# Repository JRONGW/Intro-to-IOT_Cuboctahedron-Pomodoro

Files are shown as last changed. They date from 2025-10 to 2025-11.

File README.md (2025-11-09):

# Cuboctahedron Pomodoro

A4 cuboctahedron

- The core functionality of the Cuboctahedron Pomodoro is using it as a timer for work and rest. Cuboctahedron is a symmetrical geometry representing the bi-mode of this pomodoro with its 6 identical squares and 8 identical triangles. The larger square surface down sets a 25min clock for work. The smaller triangle surface down sets a 5min clock for rest. In the testing, I use the 20s as a substitution for 25min clock and 10s as a substitution for 5min clock.

### Instruction for users
- Place the object with a square face down to start a work session.
- Place it with a triangle face down to start a rest session.
- Hold a face steady for 10 s (demo mode) to confirm; LEDs and the website visualize the state.
- (Production timings: 25 min work, 5 min rest; demo timings: 20 s / 10 s.)

### Merits
- It connects physical interaction, edge computing, event-driven networks and visualization into a closed loop.
- Edge-side filtering + hysteresis + dwell time can eliminate "false triggering" at the device end and reduce the noise of uplink data (the value of edge computing).
Robustness
####  Robustness1: Unit-vector normalization + zero-guard: 
- I compute n2 and bail if it’s ≈0, then normalize → prevents NaNs and ensures stable dot products. If I don’t normalize the accelerometer vector, the direction test gets contaminated by magnitude, which breaks thresholds, hysteresis, and dwell logic. Because the thresholds are set assuming that the n2 is normalized
####  Robustness2: LPF + re-normalize: 
- exponential smoothing (LPF_ALPHA) damps jitter; re-normalizing keeps math stable.
####  Robustness3: Hysteresis (ENTER_TH/EXIT_TH): 
- avoids flicker when the score hovers near the threshold.
####  Robustness4: 10-second dwell confirmation (DWELL_MS): 
- suppresses false triggers from bumps.
####  Robustness5: Re-arm dip (REARM_DROP_MS)
- After confirming a face, don’t consider any new face until the current face’s score has dipped below a lower threshold (EXIT_TH) for at least REARM_DROP_MS milliseconds.
####  Robustness6: Last-confirmed suppression: 
- ignores the same face immediately after confirming it to prevent repeats.

### Demerits
- The function of the pomodoro needs to be explained to the user.

### Message to MQTT
#### 1)72-LED frame bytes (binary)
 - Topic: student/CASA0014/luminaire/<user>
 - (built into mqtt_data_topic as "%s/%d" % (mqtt_base_topic, LUMINAIRE_USER))
 - Payload: raw binary buffer frameBuf of length 216 bytes (= 72 LEDs × 3 bytes per LED).
 - Format per LED: GRB order (that’s how NeoPixel expects it):
 - [G0, R0, B0,  G1, R1, B1,  ...  G71, R71, B71]
 - When sent: every time  call publishFrame() from  effect loops.
 - It shows as a blob of bytes that can be toggled to hex

#### 2)JSON “telemetry/commands” for status/timer
- These are the two snprintf(...) payloads published to mqtt_cmd_topic:
- Timer/transition message (called in updateEffects() when switching modes):
 - Example payload:
 - {"device":"MKR1010_Cubo_FaceEffects","cmd":"timer","palette":"row_temporal_grad","seconds":20,"face":"+X"}
 - {"device":"MKR1010_Cubo_FaceEffects","cmd":"timer","palette":"grad_chaser","seconds":0,"face":"square"}
- State/lock message (sent on 10-second confirmation):
 -  {"device":"MKR1010_Cubo_FaceEffects","cmd":"state","face":"+X","type":"square","score":0.913,"valid":true,"locked":true}

#### 3)Control inputs to listen for: /user and /brightness (plain numbers).

### Design
- The design follows the design principle that form follows functions in architecture. This geometry works as an abstract switch with correspondence from shape to time. 
- The larger surface with 4 edges means a longer time of working mode. The smaller surface with 3 edges means a shorter time of working mode.

### What I learned
- While making my prototype, I learned to design an algorithm to distinguish the faces from the sensor data. I tried ypr angles and acceleration. The acceleration worked. 

#### Algorithm for face detection using acceleration from IMU(MPU 6050)
- Maximizing -cos(θ) finds the θ when θ ≈ π (180°): the vectors are opposite.
- So the code is effectively finding the face whose outward normal n is most opposite to gravity g—equivalently, the face whose inward normal -n is most aligned with g.
- It’s picking the one closest to -N6[i] (i.e., the face that’s pointing down). The same logic is then repeated for the 8 triangle-face normals in N8.

 

# Circuit in Progress





# Video of Progress



Face detection tested successfully:
https://github.com/user-attachments/assets/b0937933-bc55-468b-9377-7d1f1f2e085a



Cuboctahedron Pomodoro to Vespera
https://github.com/user-attachments/assets/1aa174da-ec46-4a6b-9827-48664f9fa585



Effects updated
https://github.com/user-attachments/assets/3790d0ce-7d41-47c6-a9a7-6038a02cd146



Lid, button, and Lipo battery added, timer is represented with a gradual fill
https://github.com/user-attachments/assets/802b1e29-6ce2-49ec-8bdd-a41c0206a4fa

# Code for Face Detection, MQTT Connection, and Light Control - lightconnect.ino
## Hardware/Overall Structure
- Device Layer: MKR WiFi 1010 (WiFiNINA module + on-board RGB), MPU-6050 (accelerometer).
- Connection Layer: MQTT (tcp 1884).
- Application Layer: 72-pixel matrix web page + Vespera device (216-byte RGB frame), achieving synchronous visualization of "digital twin".

## 72 Pixels and Frame Buffer
- One-dimensional buffer frameBuf[216], logically mapped as 6 rows × 12 columns.
- Index function: idxFromRowCol(r,c) = c*6 + r (column-major order, 6 pixels per column).
- After each rendering, it is pushed to the web page/device via mqttClient.publish(mqtt_data_topic, frameBuf, 216).

## Wi-Fi and MQTT connection
- The `ensureWiFi()` function continuously attempts to connect; once successful, it lights up the on-board green LED (PWM pins 25/26/27 of NINA). 
- The `ensureMQTT()` function tries to connect every 5 seconds; upon success, it subscribes to three types of topics.

## IMU orientation determination ("which side is down")
### Sampling and Normalization
- Read the raw acceleration (ax, ay, az), and normalize it to (gx, gy, gz) ≈ the gravity direction vector at 16384 LSB/g.
- Low-pass filtering: Apply a first-order IIR smoothing with LPF_ALPHA = 0.20 and renormalize to suppress jitter.
### Face Vector Library
- 6 square face normals: ±X, ±Y, ±Z.
- 8 triangular face normals: Unit vectors in the cube's body diagonal directions (±1, ±1, ±1)/√3.
### Matching Criterion: Seek the face with the maximum -dot(n, g).
- If a face normal n is approximately opposite to the current gravity g, a larger -dot(n, g) indicates that the face is more "correctly" facing down.
### Hysteresis and Stability
- Enter threshold ENTER_TH = 0.80, exit threshold EXIT_TH = 0.72 (to prevent oscillation).
- Prevent "re-triggering on the same face": After confirming a face, the next confirmation must be on a different face.
### Dwell Confirmation (to avoid false triggers)
- A confirmation is only made after remaining on the same candidate face for 10 seconds (DWELL_MS).
- Upon confirmation, start the corresponding visual program (square → work mode, triangle → rest mode).

# Testing Codes
### Test I²C - I2Cscanner0.ino
- That’s an I²C bus scanner. It tests whether anything is alive on the I²C lines and what 7-bit addresses they respond to.
- What it verifies:
-   Wiring & power: SDA/SCL connected correctly, device powered, grounds tied together.
-   Device presence & address: prints any responding address (e.g., MPU-6050 at 0x68; 0x69 if AD0=HIGH).
-   Bus health: if nothing shows, there may be shorts, missing pull-ups, wrong voltage, or a stuck device.

### Test MPU-6050 and I²C wiring - minimaltestMakeINTeasytocatch.ino
- This sketch is a hardware/debug probe for  MPU-6050 DATA_RDY interrupt and I²C wiring. It checks three things:
- What it sets up
-   I²C comms to the MPU-6050 at address 0x68 (change to 0x69 if AD0=HIGH).
-   INT pin behavior on the MPU:
-   Enables DATA_RDY interrupt (INT_ENABLE = 0x01).
-   Tries to set: active-HIGH, push-pull, latched until cleared, clear-on-INT_STATUS read (via the library calls).
-   MCU interrupt line: connects MPU’s INT pin → MKR1010 D2, and attaches attachInterrupt(..., RISING) to catch edges.
- What it prints (and why)
-   On setup() it reads key registers directly (even if the lib lacks getByte):
-   WHO_AM_I → should be 0x68 (or 0x69 depending on variant).
-   PWR_MGMT_1 → expect 0x00 if not sleeping.
-   INT_ENABLE → expect 0x01 (DATA_RDY enabled).
-   INT_PIN_CFG → shows pin config bits (latch, polarity, etc.).

### Test MPU-6050 angle - mpu6050_mkr1010_new.ino
-   This tests printing the ypr angles from MPU-6050

### Test the face detection with UNO when MKR1010 is broken - unotest.ino
-   This tests which face is down using MPU-6050 and Arduino UNO

### Test the face detection with UNO when MKR1010 is broken - quickserialsanitytest.ino
-   It’s a tiny Serial + timing test for MKR1010.
-   What it verifies:
-   USB Serial link works: Serial.begin(115200) opens the port; 
-   while (!Serial) {} waits until the Serial Monitor is opened.
-   Board is running and not crashing: you’ll see a steady stream of prints.
-   Timing with millis() is sane: it prints once per second using a non-blocking timer.

### Test the MPU-6050 exporting - MPU6050exporttest.ino
-   I²C wiring & power
-     Wire.begin(); Wire.setClock(400000); mpu.initialize(); mpu.testConnection()//Confirms the chip responds on I²C (0x68/0x69) at 400 kHz.
-   DMP firmware load & configuration

-     mpu.dmpInitialize(); mpu.setDMPEnabled(true); packetSize = mpu.dmpGetFIFOPacketSize();//Ensures the on-chip DMP successfully boots and outputs fixed-size packets (typically 42 bytes).
-   FIFO health
-     fifoCount = mpu.getFIFOCount(); ... if (fifoCount == 1024) resetFIFO();//Checks for overflows
-   Quaternion → gravity → YPR math
-     dmpGetQuaternion(&q, fifoBuffer);
-     dmpGetGravity(&gravity, &q);
-     dmpGetYawPitchRoll(ypr, &q, &gravity);//Confirms the DMP orientation solution is coherent and  derives yaw, pitch, roll.
-   Streaming/throughput check: prints YPR at ~20 Hz (if (now - last >= 50)) to make sure Serial USB isn’t the bottleneck.

## Effect state machine (EFFECT_*)
-   EFFECT_SQUARE (20 s): "Row scan + row color breathing"
-   EFFECT_TRIANGLE (10 s): "Veered single-pixel column drift" (added the veeredSinglePerColGradient effect)
-   EFFECT_YELLOW: "5-pixel gradient chase (black ↔ yellow ↔ black)"

## Effect functions
### Row "Blink Through" Gradient - rowBlinkThrough()
-   Core idea: Instead of moving the "gradient stripes", the active row/column itself "breathes" between colors A and B over time.
-   Background: Static gradient from white to the target color (row: #FBE9D7; column: #E0F4FF) to enhance the layering effect.
-   Renderer:
-   rowBlinkThrough(r, a, b, bgTarget, t): First draw the column-wise gradient for the entire background, then overlay the r-th row with lerp(a, b, t).

### diagonal drift single pixel + vertical halo - veeredSinglePerColGradient()
-   veeredSinglePerColGradient(startCol, windowCols, baseRow, veer, a, b, radius)
-   Each column lights up one pixel and scrolls with time starting from startCol.
-   Every DRIFT_EVERY steps, baseRow moves down, forming a diagonal "snake-like" drift.
-   The upper and lower parts of the same column create a halo that gradually fades to black with a radius, enhancing the three-dimensional effect.
-   Visually, it is more dynamic than fixed "column strips".

### The "Chaser" and "Flip Every Lap" - chaserWindow()
-   chaserWindow(start, 5, a, b): A 5-pixel window advances in a 72-pixel loop.
-   chaseFlip flips a ↔ b every lap, creating an alternating pattern of light blue ↔ black ("color change every lap").
-   synchronized the on-board RGB to the tail color cB, creating a mini debug/heartbeat indicator, which is very practical.

# Design Files
-   Cuboctahedron Components folder - contains stl files of componets
-   Cuboctahedron Pomodoro.3dm -  cuboctahedron pomodoro prototype model file

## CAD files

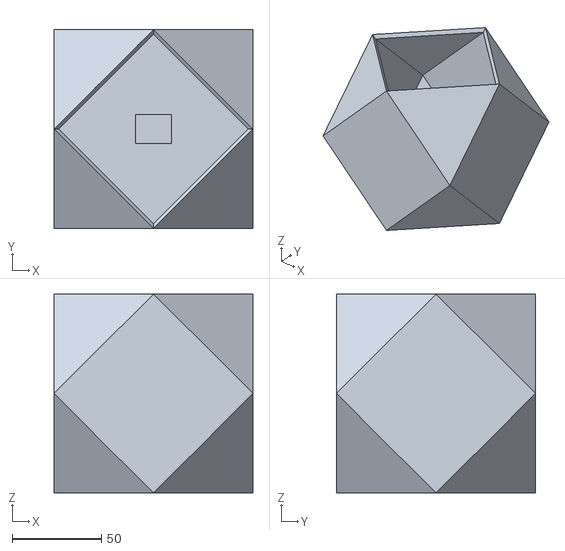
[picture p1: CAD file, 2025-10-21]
Cuboctahedron Components/main.stl
111.4 x 111.4 x 111.4

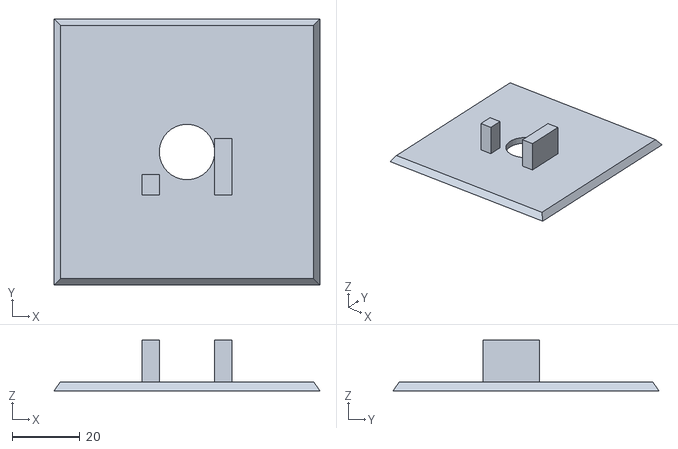
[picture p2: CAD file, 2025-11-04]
Cuboctahedron Components/lidwithhole.stl
78.7 x 78.8 x 15.0

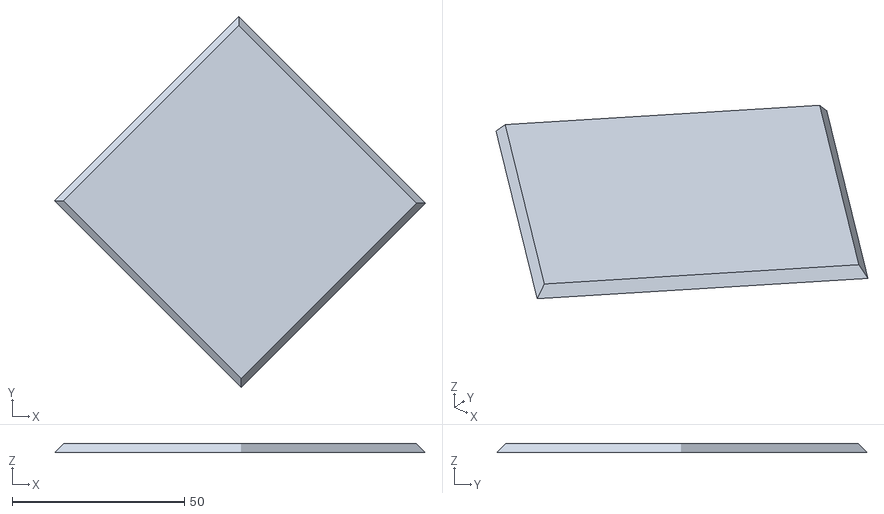
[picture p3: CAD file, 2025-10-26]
Cuboctahedron Components/lid2.stl
107.8 x 107.8 x 2.65

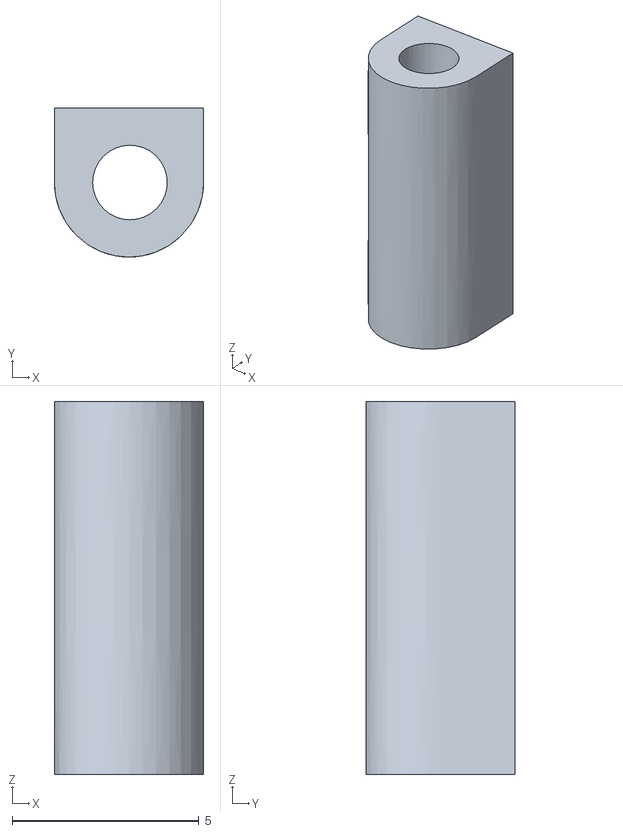
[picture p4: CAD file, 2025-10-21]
Cuboctahedron Components/hinge2.stl
4.00 x 4.00 x 10.0

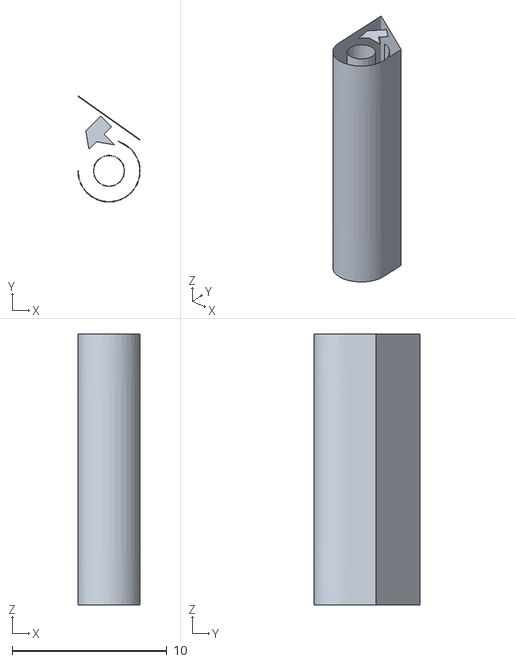
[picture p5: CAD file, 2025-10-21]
Cuboctahedron Components/hinge1.stl
4.00 x 6.83 x 17.5

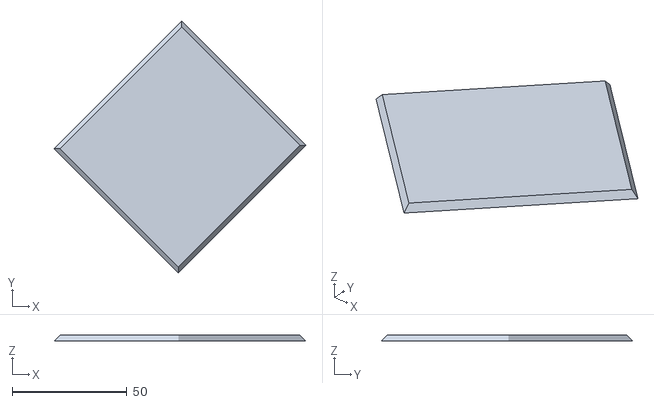
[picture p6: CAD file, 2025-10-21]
Cuboctahedron Components/lid.stl
110.0 x 110.0 x 2.65

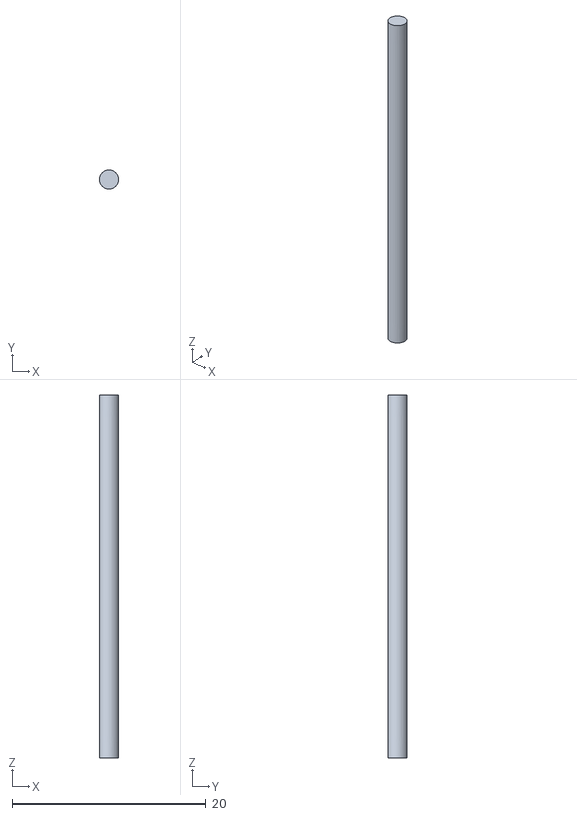
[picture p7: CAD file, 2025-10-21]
Cuboctahedron Components/pole.stl
1.98 x 1.98 x 37.5

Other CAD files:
Cuboctahedron Components/lidwithhole.gcode.3mf
Cuboctahedron Components/Lidwithhole.3dm
Cuboctahedron Components/lid with button hole.3dm
Cuboctahedron Pomodoro.3dm

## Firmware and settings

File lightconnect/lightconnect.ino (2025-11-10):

/***************************************************************
 * MKR WiFi 1010 + MPU-6050 (GY-521) — Cuboctahedron Face Detection
 * + WiFiNINA + MQTT (tcp 1884) + 72-pixel Website Effects
 *
 * Square DOWN   → Row blink-through #F6D5F7 ↔ #FBE9D7 (white→#FBE9D7 bg)
 * Triangle DOWN → Column blink-through #CAD0FF ↔ #E0F4FF (white→#E0F4FF bg)
 * Then 5-pixel gradient chaser that alternates light blue ↔ black each lap
 ***************************************************************/
#include <Wire.h>
#include <math.h>
#include "I2Cdev.h"
#include "MPU6050.h"

#include <SPI.h>
#include <WiFiNINA.h>
#include <PubSubClient.h>
#include <Adafruit_NeoPixel.h>
#include <utility/wifi_drv.h>

#include "arduino_secrets.h"  // SECRET_SSID / SECRET_PASS (+ optional MQTT_USERNAME / MQTT_PASSWORD)

/********* WIFI *********/
char ssid[] = SECRET_SSID;
char pass[] = SECRET_PASS;

/********* MQTT *********/
static const char* MQTT_HOST = "mqtt.cetools.org";
static const int   MQTT_PORT = 1884;  
static const char* MQTT_CLIENTID = "MKR1010_Cubo_FaceEffects";

#ifdef MQTT_USERNAME
  #define HAS_MQTT_AUTH 1
#else
  #define HAS_MQTT_AUTH 0
#endif

WiFiClient wifiClient;
PubSubClient mqttClient(wifiClient);

/********* Topics *********/
const char* mqtt_cmd_topic         = "student/CASA0014/luminaire/cmd";
const char* mqtt_base_topic        = "student/CASA0014/luminaire";
const char* user_update_topic      = "student/CASA0014/luminaire/user";
const char* brightness_update_topic= "student/CASA0014/luminaire/brightness";

/********* User & local-mirror *********/
int  LUMINAIRE_USER       = 25;   // change if needed
int  LUMINAIRE_BRIGHTNESS = 150;  // 0..255 (local mirror only)
char mqtt_data_topic[64];         // student/CASA0014/luminaire/<user>

/********* Website “virtual strip” *********/
#define NEOPIXEL_COUNT 72
#define NEOPIXEL_DATA_LENGTH (NEOPIXEL_COUNT * 3)
uint8_t frameBuf[NEOPIXEL_DATA_LENGTH];

/********* Optional local mirror strip *********/
#define NEOPIXEL_PIN 6
Adafruit_NeoPixel pixels(NEOPIXEL_COUNT, NEOPIXEL_PIN, NEO_GRB + NEO_KHZ800);

/********* IMU *********/
MPU6050 mpu;  // default address 0x68

/********* FACE NORMALS *********/
const float N6[6][3] = {
  { 1, 0, 0 }, { -1, 0, 0 }, { 0, 1, 0 }, { 0, -1, 0 }, { 0, 0, 1 }, { 0, 0, -1 }
};
const char* N6name[6] = { "+X", "-X", "+Y", "-Y", "+Z", "-Z" };

const float sN = 0.57735026919f;  // 1/sqrt(3)
const float N8[8][3] = {
  { sN, sN, sN }, { sN, sN, -sN }, { sN, -sN, sN }, { sN, -sN, -sN },
  { -sN, sN, sN }, { -sN, sN, -sN }, { -sN, -sN, sN }, { -sN, -sN, -sN }
};
const char* N8name[8] = {
  "+ + +", "+ + -", "+ - +", "+ - -",
  "- + +", "- + -", "- - +", "- - -"
};

/********* Detection thresholds & timing *********/
const float ENTER_TH   = 0.80f;
//entry threshold for detecting a face as ‘down’
//arccos(0.80) ≈ 36.9°

const float EXIT_TH    = 0.72f;
//exit threshold for leaving that face
//arccos(0.72) ≈ 44.0°

//So a face is conunted as ‘down’ if its normal is within 36.9 degrees
//It stays down until you tilt it past 44 degrees

// ENTER_TH and EXIT_TH creates a 7.1 degree hysteresis band that prevents flicker/rapid toggling when you are near the boundary


const float LPF_ALPHA  = 0.20f;
//this is the smoothing factor for the exponential 
//moving average(EMA) on the gravity vector

const unsigned long DWELL_MS       = 10000UL;  // 10 s confirm
const unsigned long REARM_DROP_MS  = 800UL;

struct FaceState {
  bool  isSquare;
  int   idx;
  float score;
};

static inline float invSqrt(float x) { return 1.0f / sqrtf(x); }
static inline bool sameFace(const FaceState& a, const FaceState& b) {
  return (a.idx == b.idx) && (a.isSquare == b.isSquare);
}

/*** Detection state ***/
FaceState currentFace   = { true, -1, -1.0f };
bool      haveLPF       = false;
float     gx_f=0, gy_f=0, gz_f=0;

FaceState dwellCandidate= { true, -1, -1.0f };
unsigned long dwellStartMs = 0;

FaceState lastConfirmed = { true, -1, -1.0f };

unsigned long belowStartMs = 0;
bool belowActive = false;

/********* Effect program *********/
const unsigned long DURATION_SQUARE_MS   = 20000UL; // 20 seconds
const unsigned long DURATION_TRIANGLE_MS = 10000UL; // 10 seconds

const unsigned long SCAN_PERIOD_MS  = 150UL; // every 150 ms advance row/column
const unsigned long CHASE_PERIOD_MS = 80UL;  // every 80 ms advance chaser

bool programRunning = false, programIsSquare = false;
unsigned long programStart = 0, effectStartMs = 0;

unsigned long animStartTriangle = 0;

// button control
const int BTN_PIN = 7;          // D7 connected to DFR0785-G "D"
const unsigned long DEBOUNCE_MS = 30;
const bool BTN_ACTIVE_HIGH = true;   // if your reading is inverted, flip to false

volatile bool detectEnabled = true;
volatile bool g_logFrameOnce = false;   // reset at loop start; first publish prints

unsigned long btnLastChange = 0;
bool btnPrev = LOW;             // module idles LOW (not pressed)

//-----------
enum EffectMode { EFFECT_IDLE, EFFECT_SQUARE, EFFECT_TRIANGLE, EFFECT_YELLOW };
EffectMode effect = EFFECT_IDLE;

bool yellowLatched = false; 

// variables
int  scanRow  = 0;   // 0..5
int  scanCol  = 0;   // 0..11
int  chaseIdx = 0;   // 0..71
unsigned long lastStepMs = 0;

/*** Temporal gradient blink state ***/
float rowBlinkT = 0.0f; int rowBlinkDir = 1;
float colBlinkT = 0.0f; int colBlinkDir = 1;
const float BLINK_DELTA = 0.12f;

/********* Onboard RGB helpers (via NINA) — 25=R, 26=G, 27=B *********/
static inline void setRGB(uint8_t r, uint8_t g, uint8_t b) {
  WiFiDrv::pinMode(25, OUTPUT);
  WiFiDrv::pinMode(26, OUTPUT);
  WiFiDrv::pinMode(27, OUTPUT);
  WiFiDrv::analogWrite(25, r);
  WiFiDrv::analogWrite(26, g);
  WiFiDrv::analogWrite(27, b);
}
static inline void LedRed()    { setRGB(155, 0, 0); }
static inline void LedGreen()  { setRGB(0, 155, 0); }
static inline void LedBlue()   { setRGB(0, 0, 155); }
static inline void LedYellow() { setRGB(255, 255, 0); }
static inline void LedWhite()  { setRGB(255, 255, 255); }

/********* Color + FX helpers *********/
struct Color { uint8_t r, g, b; };
const Color WHITE = { 255, 255, 255 };

// Row gradient
const Color GRAD_ROW_A = { 0xFC, 0x99, 0xFF };  // #FC99FF
const Color GRAD_ROW_B = { 0xFF, 0xA7, 0x4F };  // #FFA74F

const Color GRAD_BG_A = {0xF8, 0x9B, 0x29}; // #F89B29 (top) 
const Color GRAD_BG_B = {0xE7, 0x61, 0xBD}; // #E761BD (bottom)

// Column gradient (not used in progressive, kept for compat)
const Color GRAD_COL_A = { 0xCA, 0xD0, 0xFF };  // #CAD0FF
const Color GRAD_COL_B = { 0xE0, 0xF4, 0xFF };  // #E0F4FF

// Chaser endpoints
const Color GRAD_CHASE_B = { 0xF8, 0xFF, 0xBD }; // #f8ffbd
const Color GRAD_CHASE_A = { 0x00, 0x00, 0x00 };  // black

// gradient for triangle surface (L→R)
const Color BG_LR_A = {0x83, 0xF5, 0xE5}; // #83F5E5 
const Color BG_LR_B = {0xE7, 0x61, 0xBD}; // #E761BD

class FX {
public:
  static inline Color lerp(const Color& a, const Color& b, float t) {
    if (t < 0) t = 0; if (t > 1) t = 1;
    Color c;
    c.r = (uint8_t)(a.r + (b.r - a.r) * t);
    c.g = (uint8_t)(a.g + (b.g - a.g) * t);
    c.b = (uint8_t)(a.b + (b.b - a.b) * t);
    return c;
  }

  static inline void fillSolid(uint8_t r, uint8_t g, uint8_t b) {
    for (int i = 0; i < NEOPIXEL_COUNT; i++) {
      frameBuf[i * 3 + 0] = r;
      frameBuf[i * 3 + 1] = g;
      frameBuf[i * 3 + 2] = b;
    }
  }
  

  static inline int idxFromRowCol(int r, int c) { return c * 6 + r; }

  // Row blink-through: background = ROW gradient (WHITE->bgTarget); active row = lerp(a,b,t)
  static void rowBlinkThrough(int r, const Color& a, const Color& b, const Color& bgTarget, float t) {
    if (r < 0) r = 0;
    if (r > 5) r = 5;

    // Fill background: each row has a single uniform color
    for (int rr = 0; rr < 6; rr++) {
      float tr = (6 > 1) ? (float)rr / 5.0f : 0.0f;   // 0..1 by row
      Color cc = lerp(WHITE, bgTarget, tr);
      for (int c = 0; c < 12; c++) {
        int i = idxFromRowCol(rr, c);
        frameBuf[i * 3 + 0] = cc.r;
        frameBuf[i * 3 + 1] = cc.g;
        frameBuf[i * 3 + 2] = cc.b;
      }
    }

    // Override active row with the blink color, uniformly across the row
    Color rc = lerp(a, b, t);
    for (int c = 0; c < 12; c++) {
      int i = idxFromRowCol(r, c);
      frameBuf[i * 3 + 0] = rc.r;
      frameBuf[i * 3 + 1] = rc.g;
      frameBuf[i * 3 + 2] = rc.b;
    }
  }

  // Progressive background fill (top → bottom):
  // - Rows [0 .. rowsToFill-1] show the top→bottom gradient color for that row.
  // - Rows [rowsToFill .. 5] remain WHITE (not yet revealed).
  // Then overlay the active blink row 'r'.
  static void rowBlinkThroughProgressive(int r, const Color& a, const Color& b, float t, int rowsToFill) {
    if (r < 0) r = 0;
    if (r > 5) r = 5;
    if (rowsToFill < 0) rowsToFill = 0;
    if (rowsToFill > 6) rowsToFill = 6;

    for (int rr = 0; rr < 6; rr++) {
      // Compute the per-row gradient factor (top=0 → bottom=1)
      float tr = (6 > 1) ? (float)rr / 5.0f : 0.0f;

      // If this row is already "revealed", use its gradient color; else keep white
      Color rowColor = (rr < rowsToFill) ? lerp(GRAD_BG_A, GRAD_BG_B, tr) : WHITE;

      // Paint the whole row with that color
      for (int c = 0; c < 12; c++) {
        int i = idxFromRowCol(rr, c);
        frameBuf[i * 3 + 0] = rowColor.r;
        frameBuf[i * 3 + 1] = rowColor.g;
        frameBuf[i * 3 + 2] = rowColor.b;
      }
    }

    // Overlay active row with the blink color (uniform across the row)
    Color rc = lerp(a, b, t);
    for (int c = 0; c < 12; c++) {
      int i = idxFromRowCol(r, c);
      frameBuf[i * 3 + 0] = rc.r;
      frameBuf[i * 3 + 1] = rc.g;
      frameBuf[i * 3 + 2] = rc.b;
    }
  }



  // X-pixel gradient chaser window; black elsewhere
  static void chaserWindow(int startIdx, int window, const Color& a, const Color& b) {
    fillSolid(0, 0, 0);
    if (window < 1) window = 1;
    for (int k = 0; k < window; k++) {
      int i = (startIdx + k) % NEOPIXEL_COUNT;
      float t = (window > 1) ? (float)k / (float)(window - 1) : 0.0f;
      Color cc = lerp(a, b, t);
      frameBuf[i * 3 + 0] = cc.r;
      frameBuf[i * 3 + 1] = cc.g;
      frameBuf[i * 3 + 2] = cc.b;
    }
  }

  static inline Color toGray(const Color& c) {
    uint8_t y = (uint8_t)((0.2126f * c.r) + (0.7152f * c.g) + (0.0722f * c.b) + 0.5f);
    return { y, y, y };
  }

  // Colored stripe uses L→R palette (#83F5E5 → #E761BD).
  // Unrevealed columns = greyscale; revealed = color. Background black.
  static void veeredSinglePerColGradientProgressive(int startCol, int windowCols,
                                                    int baseRow, int veer,
                                                    const Color& /*centerFallback*/,
                                                    const Color& haloTarget,   // pass BLACK
                                                    int radius,
                                                    int colsToReveal) {
    if (windowCols < 1) windowCols = 1;
    if (radius < 0) radius = 0;
    if (colsToReveal < 0) colsToReveal = 0;
    if (colsToReveal > 12) colsToReveal = 12;

    // Background black
    fillSolid(0, 0, 0);

    // Draw moving diagonal, column by column
    for (int k = 0; k < windowCols; ++k) {
      const int c = (startCol + k) % 12;                       // 0..11
      const int centerR = ((baseRow + k * veer) % 6 + 6) % 6;  // 0..5

      float tc = (12 > 1) ? (float)c / 11.0f : 0.0f;
      Color colCenterBase = lerp(BG_LR_A, BG_LR_B, tc);
      bool revealed = (c < colsToReveal);

      Color colCenter = revealed ? colCenterBase : toGray(colCenterBase);

      // Center pixel
      {
        int i = idxFromRowCol(centerR, c);
        frameBuf[i * 3 + 0] = colCenter.r;
        frameBuf[i * 3 + 1] = colCenter.g;
        frameBuf[i * 3 + 2] = colCenter.b;
      }

      // Vertical halo within same column
      if (radius > 0) {
        for (int d = 1; d <= radius; ++d) {
          float tHalo = (float)d / (float)radius;                  // 0→1
          Color haloBase = lerp(colCenterBase, haloTarget, tHalo); // fade to black
          Color halo     = revealed ? haloBase : toGray(haloBase);

          int rUp = centerR - d;
          if (rUp >= 0) {
            int iUp = idxFromRowCol(rUp, c);
            frameBuf[iUp * 3 + 0] = halo.r;
            frameBuf[iUp * 3 + 1] = halo.g;
            frameBuf[iUp * 3 + 2] = halo.b;
          }
          int rDn = centerR + d;
          if (rDn <= 5) {
            int iDn = idxFromRowCol(rDn, c);
            frameBuf[iDn * 3 + 0] = halo.r;
            frameBuf[iDn * 3 + 1] = halo.g;
            frameBuf[iDn * 3 + 2] = halo.b;
          }
        }
      }
    }
  }
}; // end class FX

/********* Publish / mirror *********/
bool publishFrame() {
  if (!mqttClient.connected()) {
    if (g_logFrameOnce) { Serial.println("[MQTT] Not connected; frame NOT published."); g_logFrameOnce = false; }
    return false;
  }
  bool ok = mqttClient.publish(mqtt_data_topic, frameBuf, NEOPIXEL_DATA_LENGTH);
  if (g_logFrameOnce) {
    Serial.print("[PUB] ");
    Serial.print(NEOPIXEL_DATA_LENGTH);
    Serial.print("B -> ");
    Serial.println(mqtt_data_topic);
    if (!ok) { Serial.print("  state="); Serial.println(mqttClient.state()); }
    g_logFrameOnce = false;     // print only once this loop()
  }
  return ok;
}

void showLocalMirror() {
  pixels.setBrightness(LUMINAIRE_BRIGHTNESS);
  for (int i = 0; i < NEOPIXEL_COUNT; i++) {
    pixels.setPixelColor(i,
      frameBuf[i * 3 + 0], frameBuf[i * 3 + 1], frameBuf[i * 3 + 2]);
  }
  pixels.show();
}
void publishSolidAndShow(uint8_t r, uint8_t g, uint8_t b) {
  FX::fillSolid(r, g, b);
  publishFrame();
  setRGB(r, g, b);
  showLocalMirror();
}

// centralize disable behavior
void disableDetection() {
  detectEnabled = false;
  dwellCandidate.idx = -1;
  currentFace.idx = -1;
  effect = EFFECT_IDLE;
  publishSolidAndShow(0, 0, 0);
  Serial.println("[BTN] detection DISABLED");
}
void enableDetection() {
  detectEnabled = true;
  Serial.println("[BTN] detection ENABLED");
}

/********* MQTT status JSON (optional telemetry) *********/
void publishCmdJSON(const char* palette, uint16_t seconds, const char* faceName) {
  char buf[200];
  snprintf(buf, sizeof(buf),
           "{\"device\":\"%s\",\"cmd\":\"timer\",\"palette\":\"%s\",\"seconds\":%u,\"face\":\"%s\"}",
           MQTT_CLIENTID, palette, seconds, faceName ? faceName : "");
  mqttClient.publish(mqtt_cmd_topic, buf);
}
void publishState(const char* faceName, const char* faceType, float score, bool valid, bool locked) {
  char buf[220];
  snprintf(buf, sizeof(buf),
           "{\"device\":\"%s\",\"cmd\":\"state\",\"face\":\"%s\",\"type\":\"%s\",\"score\":%.3f,\"valid\":%s,\"locked\":%s}",
           MQTT_CLIENTID, faceName ? faceName : "none", faceType ? faceType : "none",
           score, valid ? "true" : "false", locked ? "true" : "false");
  mqttClient.publish(mqtt_cmd_topic, buf);
}
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
void loop() {
  ensureWiFi();
  ensureMQTT();
  mqttClient.loop();
  g_logFrameOnce = true;

  bool raw = digitalRead(BTN_PIN);
  bool btnNow = (raw == (BTN_ACTIVE_HIGH ? HIGH : LOW));
  // button control

  unsigned long now = millis();

  // debounce
  if (btnNow != btnPrev && (now - btnLastChange) > DEBOUNCE_MS) {
    btnLastChange = now;
    btnPrev = btnNow;
    if (btnNow) {             // on press
      if (!yellowLatched) latchYellowOn();
      else                latchYellowOff();
    }
  }

  // ---- EFFECTS ALWAYS RUN ----
  updateEffects();

  if (!detectEnabled) { delay(10); return; }

  // ---- IMU READ ----
  int16_t ax, ay, az;
  mpu.getAcceleration(&ax, &ay, &az);
  //When the accelerometer is configured at ±2 g range, 
  //its sensitivity is 16 384 Least Significant Bit per g. 
  //Dividing the raw readings (ax, ay, az) by 16384.0f
  //converts them from raw counts to g units 
  //(so a stationary device might read ≈ (0, 0, 1)).
  //🦜🦜🦜🦜🦜🦜🦜🦜🦜🦜🦜🦜🦜🦜


  float gx = ax / 16384.0f, gy = ay / 16384.0f, gz = az / 16384.0f;

  //Following is a safety check.
  //If the squared length is near zero, it means the vector 
  //is almost zero — maybe a bad reading, disconnected sensor, 
  //or free-fall (no gravity detected).
  //Instead of dividing by zero (which would produce NaN), 
  //it just waits a bit and skips the update.


  float n2 = gx * gx + gy * gy + gz * gz;
  if (n2 < 1e-6f) { delay(10); return; }
  //If it’s ~0, the reading is bogus (e.g., free-fall, 
  //disconnection, or transient glitch). We skip this 
  //loop to avoid dividing by ~0 later.

  float invn = invSqrt(n2);
  gx *= invn; gy *= invn; gz *= invn;

  // now ||(gx,gy,gz)|| = 1, 
  //After this, (gx, gy, gz) is a unit gravity direction vector.
  //After this, (gx, gy, gz) is a direction vector pointing along 
  //measured gravity, with length ≈ 1.
  //This is perfect for dot-product face detection because it 
  // removes amplitude variation.


  // Low-pass + renormalize
  // Low-pass = smoothing: It removes high-frequency 
  // jitter/noise and short bumps from the accelerometer 
  // so the “which face is down” logic doesn’t flicker.
  // LPF_ALPHA is the smoothing factor.


  // Low-pass + renormalize
  if (!haveLPF) {
    gx_f = gx; gy_f = gy; gz_f = gz; haveLPF = true;
  } else {
    // 1) Low-pass (EMA / IIR(1))
    //New = (1-α)·Old + α·Current
    //Smaller LPF_ALPHA → more smoothing (slower response, less jitter).
    //Larger LPF_ALPHA → faster response (more jitter passes).

    gx_f = (1.0f - LPF_ALPHA) * gx_f + LPF_ALPHA * gx;
    gy_f = (1.0f - LPF_ALPHA) * gy_f + LPF_ALPHA * gy;
    gz_f = (1.0f - LPF_ALPHA) * gz_f + LPF_ALPHA * gz;

    // 2) Re-normalize to unit length
    float m2 = gx_f * gx_f + gy_f * gy_f + gz_f * gz_f;
    float invm = invSqrt(m2);
    gx_f *= invm; gy_f *= invm; gz_f *= invm;
  }

  // Best face = argmax -dot(n, g)
  float bestScore = -1e9f; int bestIdx = -1; bool bestIsSquare = true;

  // Squares
  for (int i = 0; i < 6; i++) {
    float dotv = N6[i][0]*gx_f + N6[i][1]*gy_f + N6[i][2]*gz_f;
    float score = -dotv;
    if (score > bestScore) { bestScore = score; bestIdx = i; bestIsSquare = true; }
  }
  // Triangles
  for (int i = 0; i < 8; i++) {
    float dotv = N8[i][0]*gx_f + N8[i][1]*gy_f + N8[i][2]*gz_f;
    float score = -dotv;
    if (score > bestScore) { bestScore = score; bestIdx = i; bestIsSquare = false; }
  }

  // Hysteresis tracking for currentFace
  if (currentFace.idx == -1) {
    // Not tracking → only lock when a candidate is clearly good
    if (bestScore > ENTER_TH) {
      currentFace.isSquare = bestIsSquare;
      currentFace.idx      = bestIdx;
      currentFace.score    = bestScore;
      belowActive = false;
    }
  } else {
    // Already tracking
    if (bestIsSquare == currentFace.isSquare && bestIdx == currentFace.idx) {
      // Same face still best → refresh score
      currentFace.score = bestScore;
    } else {
      // Different face is best now
      if (bestScore > ENTER_TH) {
        // New face is strong → switch
        currentFace.isSquare = bestIsSquare;
        currentFace.idx      = bestIdx;
        currentFace.score    = bestScore;
        belowActive = false;
      } else if (currentFace.score < EXIT_TH) {
        // Current face got weak → drop lock; wait for a strong re-entry
        currentFace.idx   = -1;
        currentFace.score = 0.0f;  // optional
        belowActive = false;
      }
      // else: keep tracking the current face (do nothing)
    }
  }


  bool haveCandidate = (currentFace.idx != -1) && (currentFace.score > ENTER_TH);

  // Suppress SAME face as last confirmed
  if (haveCandidate && lastConfirmed.idx != -1 && sameFace(currentFace, lastConfirmed)) {
    dwellCandidate.idx = -1;
    delay(10);
    return;
  }

  // dip re-arm (robustness)
  if (lastConfirmed.idx != -1) {
    if (currentFace.score < EXIT_TH) {
      if (!belowActive) { belowActive = true; belowStartMs = millis(); }
      else if (millis() - belowStartMs >= REARM_DROP_MS) { belowActive = false; }
    } else {
      belowActive = false;
    }
  }

  if (!haveCandidate) { dwellCandidate.idx = -1; delay(10); return; }

  unsigned long nowMs = millis();

  // Dwell accumulation on new different face
  if (dwellCandidate.idx == -1 || !sameFace(dwellCandidate, currentFace)) {
    dwellCandidate = currentFace;
    dwellStartMs   = nowMs;
  } else {
    unsigned long elapsed = nowMs - dwellStartMs;
    if (elapsed >= DWELL_MS) {
      const char* faceType = currentFace.isSquare ? "square" : "triangle";
      const char* faceName = currentFace.isSquare ? N6name[currentFace.idx] : N8name[currentFace.idx];
      Serial.print("[CONFIRMED 10s] ");
      Serial.print(faceType);
      Serial.print(" DOWN: ");
      Serial.print(faceName);
      Serial.print("   score=");
      Serial.println(currentFace.score, 3);
      publishState(faceName, faceType, currentFace.score, true, true);

      // Start the program for this face
      programIsSquare = currentFace.isSquare;
      programRunning  = true;
      programStart    = nowMs;
      lastStepMs      = 0;
      rowBlinkT = colBlinkT = 0.0f;
      rowBlinkDir = colBlinkDir = 1;

      if (programIsSquare) {
        scanRow = 0;
        effect = EFFECT_SQUARE;
        effectStartMs = nowMs;
        publishCmdJSON("row_temporal_grad", DURATION_SQUARE_MS / 1000, faceName);
      } else {
        scanCol = 0;
        effect = EFFECT_TRIANGLE;
        effectStartMs = nowMs;
        animStartTriangle = nowMs;  // set anim clock once on entry
        publishCmdJSON("col_temporal_grad", DURATION_TRIANGLE_MS / 1000, faceName);
      }

      lastConfirmed = currentFace;
      dwellCandidate.idx = -1;  // re-arm for different face
    }
  }

  delay(10);
}

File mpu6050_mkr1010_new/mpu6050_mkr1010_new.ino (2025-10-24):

#include <Wire.h>
#include "MPU6050_6Axis_MotionApps20.h"  // Rowberg DMP header

MPU6050 mpu;
bool dmpReady = false;
uint16_t packetSize;  // expected DMP packet size (usually 42)
uint16_t fifoCount;
uint8_t fifoBuffer[64];

Quaternion q;
VectorFloat gravity;
float ypr[3];

void setup() {
  Serial.begin(115200);
  while (!Serial) {}
  Wire.begin();
  Wire.setClock(400000);

  mpu.initialize();
  if (!mpu.testConnection()) {
    Serial.println("MPU connect FAIL");
    while (1) {}
  }

  // DMP init
  int status = mpu.dmpInitialize();
  if (status != 0) {
    Serial.print("DMP init fail: ");
    Serial.println(status);
    while (1) {}
  }

  // (Optional but helps) lower DMP FIFO rate to reduce overflow if available
  //mpu.dmpSetFIFORate(50);

  mpu.setDMPEnabled(true);

  // Configure INT pin behavior (not strictly needed in polling mode)
  mpu.setInterruptMode(false);       // active HIGH
  mpu.setInterruptDrive(false);      // push-pull
  mpu.setInterruptLatch(true);       // latch until cleared
  mpu.setInterruptLatchClear(true);  // clear on read of INT_STATUS

  // Enable only DMP interrupt bit in case you later use ISR
  mpu.setIntEnabled(0x02);

  packetSize = mpu.dmpGetFIFOPacketSize();
  dmpReady = true;

  Serial.print("DMP ready. packetSize=");
  Serial.println(packetSize);
}

void loop() {
  if (!dmpReady) return;

  fifoCount = mpu.getFIFOCount();

  // Handle overflow immediately
  if (fifoCount == 1024) {
    mpu.resetFIFO();
    Serial.println("FIFO overflow -> reset");
    return;
  }

  if (fifoCount < packetSize) {
    // not enough data yet
    delay(2);
    return;
  }

  // Drain all complete packets
  while (fifoCount >= packetSize) {
    mpu.getFIFOBytes(fifoBuffer, packetSize);
    fifoCount -= packetSize;

    // Parse one packet
    mpu.dmpGetQuaternion(&q, fifoBuffer);
    mpu.dmpGetGravity(&gravity, &q);
    mpu.dmpGetYawPitchRoll(ypr, &q, &gravity);

    // Print at a modest rate so Serial doesn’t bottleneck
    static uint32_t last = 0;
    uint32_t now = millis();
    if (now - last >= 50) {  // ~20 Hz print
      Serial.print("ypr\t");
      Serial.print(ypr[0] * 180.0 / M_PI);
      Serial.print('\t');
      Serial.print(ypr[1] * 180.0 / M_PI);
      Serial.print('\t');
      Serial.println(ypr[2] * 180.0 / M_PI);
      last = now;
    }
  }
}

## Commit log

2025-10-26 successfully controlled the 72 neopixels
    [lid2.stl]
2025-10-28 files arranged
    [hinge1.stl, hinge2 - second one.stl, hinge2.stl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]
2025-11-03 update with lipo;updated effects
    [Lidwithhole.3dm, lid with button hole.3dm]
2025-11-04 add button function
    [lidwithhole.gcode.3mf, lidwithhole.stl]
2025-11-10 Update lightconnect.ino for adding the button and Lipo battery, updated the effect for showing the time
